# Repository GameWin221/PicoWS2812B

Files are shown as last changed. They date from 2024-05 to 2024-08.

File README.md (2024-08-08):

# PicoWS2812B

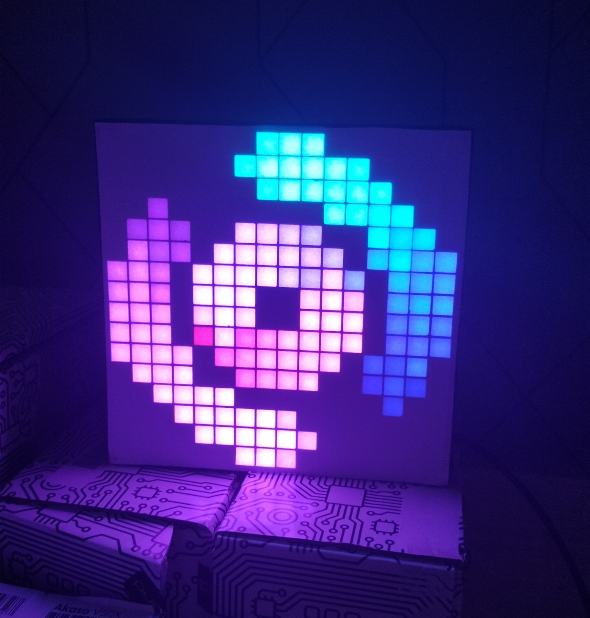
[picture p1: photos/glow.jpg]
glow


16x16 WS2812B matrix display controlled via Wi-Fi TCP socket with a Raspberry Pi Pico W. This project is my passion project but it also puts emphasis on performance and code readabilty in order to serve as a simple example for people learning. 

# Important Features
- Both 8 bits per-channel mode and 4 bits per-channel mode for lowering network usage and decreasing delay.
- TCP used instead of HTTP for additional performance.
- Seamless handling of client<->server connect / disconnect.
- Readable code that can easily be used for learning purposes.
- Images, Image sequences and GIFs can be stored in flash memory and played back offline with no interruptions.

# Controller
Any controller that uses **TCP sockets** and conforms to the **Packet Format** and the **Data Protocol** sections below will be compatible with the display. 

Take a look at the [working example of a compatible controller](https://github.com/GameWin221/pico-ws2812b-controller)

## Data Protocol
The display receives packets through a TCP socket open on port 4242 by deafault. (It can be changed)

1. Controller sends a valid packet (look at **Packet Format**) to the Pico W
2. Controller waits for a response from the Pico W
3. If the response reads exactly `"ACK"`, then the whole packet was sent and received succesfully.

After reading the correct response, the next packet can be sent immediately.

## Packet Format
Take a look at the [packet.hpp](src/packet.hpp) file to see all packet types. Mind the [default C/C++ struct alignment](https://en.wikipedia.org/wiki/Data_structure_alignment#Typical_alignment_of_C_structs_on_x86). 

The first byte (`uint8_t`) of a received packet is always the `data_type` field. Each packet type has its own unique data type.

RGB data is expected to be in the [row-major](https://en.wikipedia.org/wiki/Row-_and_column-major_order) order with (x:0, y:0) being the lower-left corner:
```
...       , ...       , ...
(x:0; y:2), (x:1; y:2), ...
(x:0; y:1), (x:1, y:1), ...
(x:0; y:0), (x:1, y:0), ...
```

8bpp (Full) RGB data layout:
```
data[0] , data[1] , data[2] , data[...]
RRRRRRRR, GGGGGGGG, BBBBBBBB, ...
```

4bpp (Half) RGB data layout:
```
data[0] , data[1] , data[2] , data[...]
RRRRGGGG, BBBBRRRR, GGGGBBBB, ...
```

## Working Example
The working example of a compatible controller can be found [here in this repository](https://github.com/GameWin221/pico-ws2812b-controller)

# Build
## Prerequisites
- Native GNU C++ compiler [(for example MinGW)](https://winlibs.com/) that is added to PATH
- [ARM GNU Toolchain](https://developer.arm.com/downloads/-/arm-gnu-toolchain-downloads) and the `PICO_TOOLCHAIN_PATH` environmental variable.
- [Pico SDK](https://github.com/raspberrypi/pico-sdk) and the `PICO_SDK_PATH` environmental variable.

## Command
Once the prerequisites are satisfied, run the following command:
```
mkdir build
cd build

cmake -G "MinGW Makefiles" .. 
make (ming32-make on Windows)
```

And copy the built .uf2 file to your Pico's Mass Storage

# Power Consumption
**Please double-check if your power supply can safely provide enough current at 5V. Note that not every WS2812B draws the same amount of current.**

Current draw was measured only at 0%, 12.5% and 25% brightness with the whole display set to RGB(255, 255, 255). Higher values were calculated by extrapolatating the measurements.

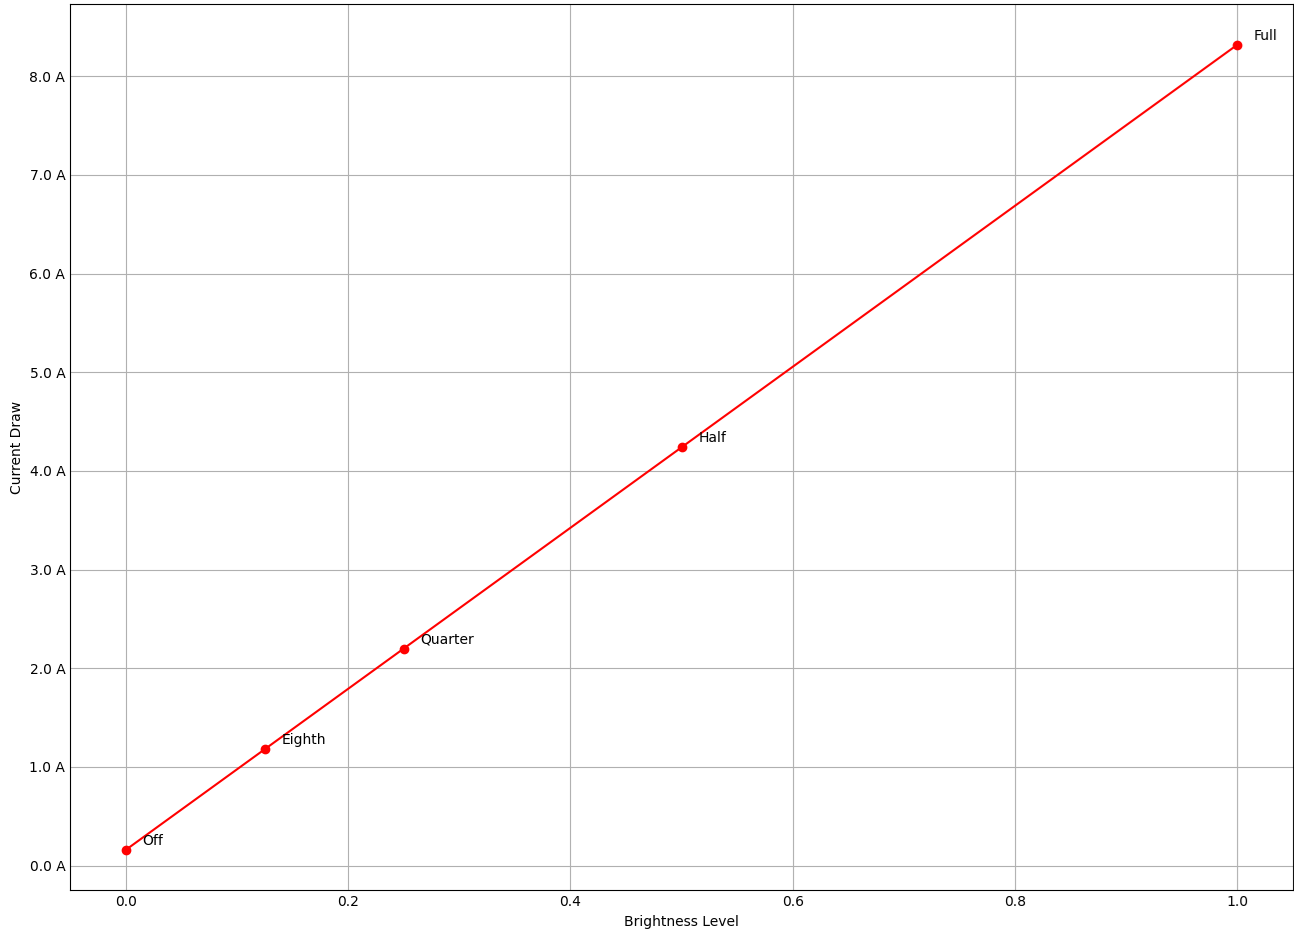
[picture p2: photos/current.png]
current


# Parts Required
- [16x16 WS2812B RGB LED Matrix](https://botland.store/led-strings-chains-matrices/6183-elastic-matrix-16x16-256-led-rgb-ws2812b-5904422374945.html)
- [Raspberry Pi Pico W](https://botland.store/raspberry-pi-pico-modules-and-kits/21574-raspberry-pi-pico-w-rp2040-arm-cortex-m0-cyw43439-wifi-5056561803173.html)
- [Short Breadboard](https://botland.store/breadoards/19942-breadboard-justpi-400-holes-5904422328627.html)
- 3 Male-Male Jumper Wires (or any other way to connect WS2812B to the Pico)
- [DC 5,5x2,1mm socket with quick connection](https://botland.store/quick-couplings/1804-dc-55x21mm-socket-with-quick-connection-5904422373238.html)
- A piece of white paper or thin plastic that works well as a light diffuser
- 3D printed frame and grid (both .stl files are in the `3dprints` directory)

## Assembly
- Put the WS2812B in between the printed `Frame.stl` and the printed `Grid.stl` so that it fits nicely
- Glue `Frame.stl` and `Grid.stl` together
- Glue the light diffuser to `Grid.stl` so that it fully covers the LEDs
- Stick the breadboard to the matrix's backside - inside `Frame.stl`
- Insert the DC socket into the dedicated hole and **correctly connect** the power cables of the LED matrix.
- Put the Raspberry Pi Pico W into the breadboard and **correctly connect** the jumper wires.

# Disclaimer
**I am not responsible for any physical damage caused by running this code. Use adequate brightness levels and double-check if your power supply can safely provide enough current in order to avoid any unwanted damage. Some WS2812B LED matrices may require more current than others. The TCP server accepts every incoming connection and every packet with no verification so it may potentially pose a threat to your local network's overall security.**

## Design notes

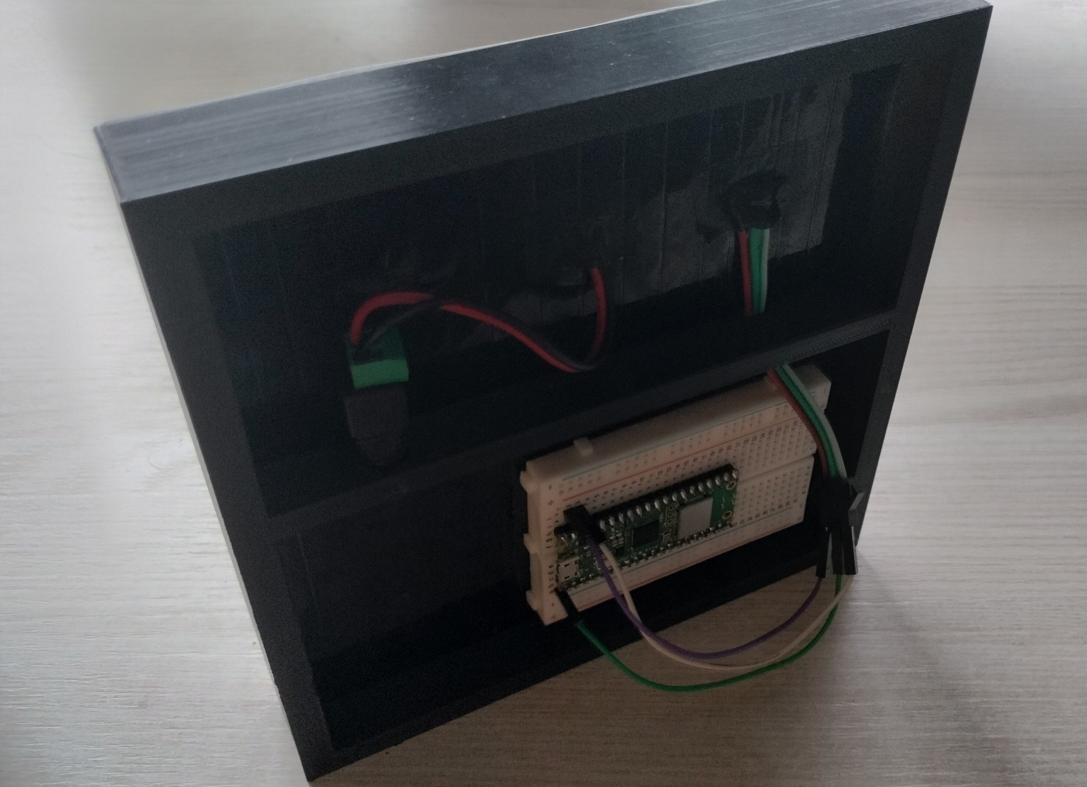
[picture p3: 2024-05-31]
photos/back.jpg

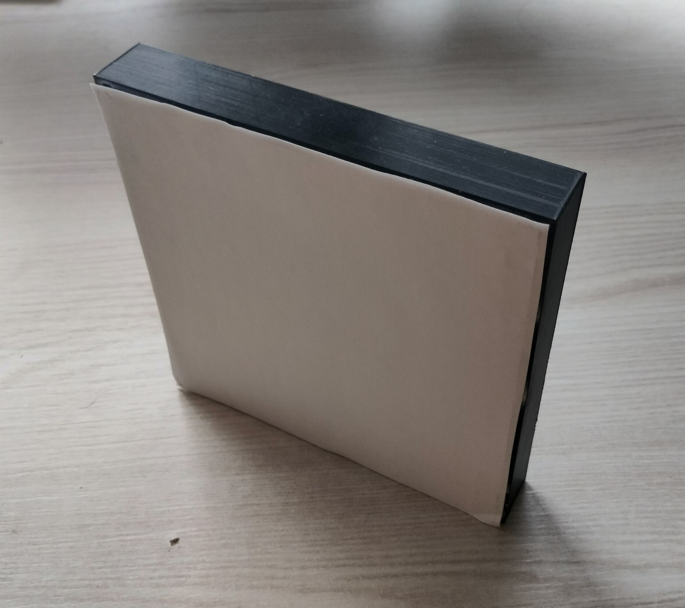
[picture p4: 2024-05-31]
photos/front.jpg

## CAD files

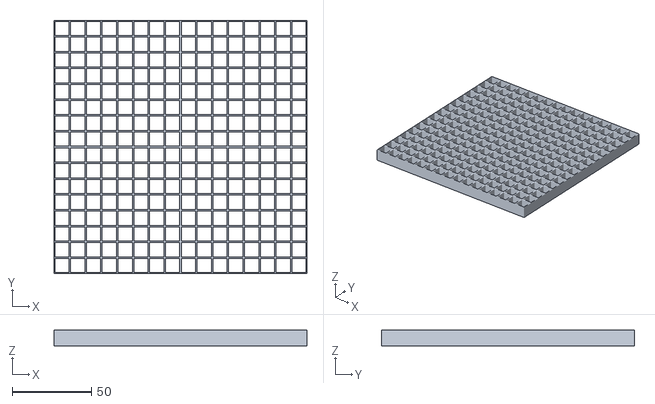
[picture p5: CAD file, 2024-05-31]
3dprints/Grid.stl
160.0 x 160.0 x 10.0

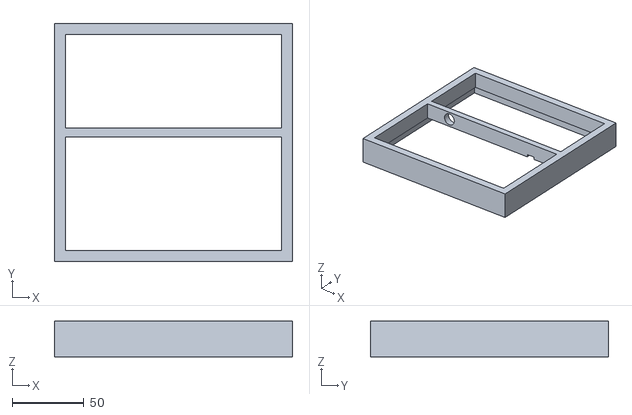
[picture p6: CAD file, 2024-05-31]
3dprints/Frame.stl
166.0 x 166.0 x 25.0

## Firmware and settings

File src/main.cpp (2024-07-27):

#include <pico/stdlib.h>
#include <pico/time.h>
#include <hardware/flash.h>
#include <hardware/sync.h>
#include <hardware/irq.h>

#include <string.h>

#include "packet.hpp"
#include "ws2812b.hpp"
#include "tcp_server.hpp"
#include "secrets.hpp" // WIFI_SSID "", WIFI_PASS ""

constexpr uint32_t DATA_PIN = 0u;
constexpr uint32_t SEVER_TIMEOUT_S = 8u;
constexpr uint16_t SEVER_PORT = 4242;

// 768KB offset
constexpr uint32_t FLASH_TARGET_OFFSET = (768u * 1024u);
static const uint8_t *flash_read_contents = (const uint8_t*)(XIP_BASE); // Adding the offset here makes read/write more inconsistent.

static repeating_timer_t flash_player_timer{};
static bool flash_player_running = false;

static uint16_t begin_frame_idx_inclusive{}; 
static uint16_t end_frame_idx_inclusive{}; 
static uint16_t time_interval_ms{};
static uint16_t current_frame_id{};

// Allows for better flash data packing and better flash wear. 
// Instead of using a whole sector per one frame, use one quarter of a sector per frame.
// Since one frame is 16*16*3 (768) bytes we only waste 25% of memory this way instead of 81.25%.
// It can be improved but it is good enough. We can store up to 1280 full 8bpp frames starting from 768KB offset.
static void write_flash_sector_quarter(uint32_t dst_sector_id, uint32_t dst_quarter_id, const uint8_t *data, uint32_t data_size) {
    if(data_size > FLASH_SECTOR_SIZE / 4u) {
        printf("write_flash_sector_quarter(uint32_t dst_sector_id, uint32_t dst_quarter_id, const uint8_t *data, uint32_t data_size) data_size cannot be larger than FLASH_SECTOR_SIZE / 4u\n");
        return;
    }

    if(dst_quarter_id > 3u) {
        printf("write_flash_sector_quarter(uint32_t dst_sector_id, uint32_t dst_quarter_id, const uint8_t *data, uint32_t data_size) dst_quarter_id msut be either 0, 1, 2 or 3\n");
        return;
    }

    const uint32_t quarter_size = FLASH_SECTOR_SIZE / 4;

    uint32_t dst_sector_offset = dst_sector_id * FLASH_SECTOR_SIZE;
    uint32_t dst_quarter_offset = dst_quarter_id * quarter_size;

    bool quarter_erased[4] = { true, true, true, true };

    for(uint32_t i{}; i < 4u; ++i) {
        for(uint32_t j{}; j < quarter_size; ++j) {
            if (flash_read_contents[FLASH_TARGET_OFFSET + dst_sector_offset + (i * quarter_size) + j] != 0xFF) {
                quarter_erased[i] = false;
                break;
            }
        }
    }

    uint32_t interrupts = save_and_disable_interrupts();

    if(quarter_erased[dst_quarter_id]) {
        flash_range_program(FLASH_TARGET_OFFSET + dst_sector_offset + dst_quarter_offset, data, data_size);
    } else {
        static uint8_t sector_copy[FLASH_SECTOR_SIZE];
        
        memcpy(sector_copy, &flash_read_contents[FLASH_TARGET_OFFSET + dst_sector_offset], FLASH_SECTOR_SIZE);
        
        flash_range_erase(FLASH_TARGET_OFFSET + dst_sector_offset, FLASH_SECTOR_SIZE);

        for(uint32_t i{}; i < 4u; ++i) {
            uint32_t src_quarter_offset = i * quarter_size;

            if(i != dst_quarter_id && !quarter_erased[i]) {
                // Restore old 3 quarters. No need to restore erased quarters.
                flash_range_program(FLASH_TARGET_OFFSET + dst_sector_offset + src_quarter_offset, &sector_copy[src_quarter_offset], quarter_size);
            } else {
                // Write new quarter data
                flash_range_program(FLASH_TARGET_OFFSET + dst_sector_offset + src_quarter_offset, data, data_size);
            }
        }
    }

    restore_interrupts(interrupts);
}

static bool flash_player_timer_callback(repeating_timer_t *rt) {
    WS2812B *led_matrix = (WS2812B*)rt->user_data;

    uint32_t current_frame_offset = (uint32_t)current_frame_id * FLASH_SECTOR_SIZE / 4u;

    for(uint32_t x{}; x < 16u; ++x) {
        for(uint32_t y{}; y < 16u; ++y) {
            uint32_t idx = y * 16u + x;

            led_matrix->set_pixel(x, y, 
                flash_read_contents[FLASH_TARGET_OFFSET + idx * 3u + 0u + current_frame_offset],
                flash_read_contents[FLASH_TARGET_OFFSET + idx * 3u + 1u + current_frame_offset],
                flash_read_contents[FLASH_TARGET_OFFSET + idx * 3u + 2u + current_frame_offset]
            );
        }
    }

    led_matrix->update_display();

    // Wrap back to the beginning
    if((++current_frame_id) > end_frame_idx_inclusive) {
        current_frame_id = begin_frame_idx_inclusive;
    }

    return true;
}

static void on_buffer_ready(const uint8_t *buf, WS2812B &led_matrix) {
    // Any incoming data will interrupt the currently playing flash player
    if(flash_player_running) {
        cancel_repeating_timer(&flash_player_timer);
        flash_player_running = false;
    }

    uint8_t buf_data_type = buf[0];

    switch(buf_data_type) {
        case DATA_TYPE_FULL: {
            const PacketFull *p = (const PacketFull*)buf;

            for(uint32_t x{}; x < 16u; ++x) {
                for(uint32_t y{}; y < 16u; ++y) {
                    uint32_t idx = y * 16u + x;

                    led_matrix.set_pixel(x, y, 
                        p->data[idx * 3u + 0u],
                        p->data[idx * 3u + 1u],
                        p->data[idx * 3u + 2u]
                    );
                }
            }

            led_matrix.update_display();
        }   break;

        case DATA_TYPE_HALF: {
            const PacketHalf *p = (const PacketHalf*)buf;

            for(uint32_t x{}; x < 16u; ++x) {
                for(uint32_t y{}; y < 16u; ++y) {
                    uint32_t idx = y * 16u + x;

                    uint8_t r = (idx % 2u == 0u) ? ((p->data[idx * 3u / 2u + 0u] & 0xf0) >> 4) :  (p->data[idx * 3u / 2u + 0u] & 0x0f);
                    uint8_t g = (idx % 2u == 0u) ?  (p->data[idx * 3u / 2u + 0u] & 0x0f)       : ((p->data[idx * 3u / 2u + 1u] & 0xf0) >> 4);
                    uint8_t b = (idx % 2u == 0u) ? ((p->data[idx * 3u / 2u + 1u] & 0xf0) >> 4) :  (p->data[idx * 3u / 2u + 1u] & 0x0f);

                    // Unpack from 4 bits to 8 bits
                    led_matrix.set_pixel(x, y, r << 4, g << 4, b << 4);
                }
            }

            led_matrix.update_display();
        }   break;

        case DATA_TYPE_WRITE_FLASH: {
            const PacketWriteFlash *p = (const PacketWriteFlash*)buf;

            uint32_t dst_sector = (uint32_t)p->frame_idx / 4u;
            uint32_t dst_quarter = (uint32_t)p->frame_idx % 4u;

            write_flash_sector_quarter(dst_sector, dst_quarter, p->data, 16u * 16u * 3u);
        } break;

        case DATA_TYPE_PLAY_FLASH: {
            const PacketPlayFlash *p = (const PacketPlayFlash*)buf;

            begin_frame_idx_inclusive = p->begin_frame_idx_inclusive;
            end_frame_idx_inclusive = p->end_frame_idx_inclusive;
            time_interval_ms = p->time_interval_ms;

            if(begin_frame_idx_inclusive > end_frame_idx_inclusive) {
                printf("main(): begin_frame_idx_inclusive cannot be greater than end_frame_idx_inclusive!\n");
                begin_frame_idx_inclusive = 0u;
                end_frame_idx_inclusive = 0u;
                
                break;
            }

            if(!add_repeating_timer_ms(-((int32_t)time_interval_ms), flash_player_timer_callback, &led_matrix, &flash_player_timer)) { 
                printf("main(): Failed to create flash_player_timer!\n");

                break;
            } else {
                flash_player_running = true;
            }
        }   break;

        default:
            printf("main(): Incorrect buf_data_type!\n");
            break;
    }
}

int main() {
    stdio_init_all();

    if (cyw43_arch_init()) {
        printf("main(): Failed to initialise cyw43_arch!\n");
        return 1;
    }
    
    cyw43_arch_enable_sta_mode();

    WS2812B led_matrix(DATA_PIN, LEDBrightness::Half);
    led_matrix.fill(64, 0, 0);
    led_matrix.update_display();

    printf("Connecting to Wi-Fi...\n");

    while(cyw43_arch_wifi_connect_timeout_ms(WIFI_SSID, WIFI_PASS, CYW43_AUTH_WPA2_AES_PSK, 10000u)) {
        printf("Failed to connect to Wi-Fi. Retrying...\n");
    }

    printf("Connected to Wi-Fi.\n");

    led_matrix.fill(64, 64, 0);
    led_matrix.update_display();

    TCPServer server{};
    if(!server.start(SEVER_PORT, SEVER_TIMEOUT_S)) {
        printf("main(): Failed to start the server. Retrying..\n");

        led_matrix.fill(0, 64, 64);
        led_matrix.update_display();

        cyw43_arch_deinit();

        return 1;
    }
    
    printf("Server started successfully!\n");
    
    led_matrix.fill(0, 64, 0);
    led_matrix.update_display();

    while(server.is_running()) {  
        cyw43_arch_poll();
        
        // Handle packets from the main thread to avoid problems (e.g. writing to flash)
        const uint8_t *buf = server.get_ready_buffer();
        if(buf != nullptr) {
            on_buffer_ready(buf, led_matrix);
        }

        cyw43_arch_wait_for_work_until(make_timeout_time_ms(100));
    }

    cyw43_arch_deinit();
}

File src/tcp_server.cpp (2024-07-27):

#include "tcp_server.hpp"
#include "packet.hpp"

// Based on the official picow_tcp_server.c example:
// https://github.com/raspberrypi/pico-examples/blob/master/pico_w/wifi/tcp_server/picow_tcp_server.c

bool TCPServer::start(uint16_t port, uint8_t _timeout_time_s) {
    printf("Starting server at %s:%u\n", ip4addr_ntoa(netif_ip4_addr(netif_list)), port);

    tcp_pcb *pcb = tcp_new_ip_type(IPADDR_TYPE_ANY);
    if (!pcb) {
        printf("TCPServer::start(uint16_t port): Failed to create the server pcb\n");
        return false;
    }

    if (tcp_bind(pcb, nullptr, port)) {
        printf("TCPServer::start(uint16_t port): Failed to bind to port: %u\n", port);
        return false;
    }
    
    server_pcb = tcp_listen_with_backlog(pcb, 1);
    if (!server_pcb) {
        printf("TCPServer::start(uint16_t port): Failed to listen for incoming clients.\n");

        tcp_close(pcb);

        return false;
    }

    timeout_time_s = _timeout_time_s;

    tcp_arg(server_pcb, this);
    tcp_accept(server_pcb, TCPServer::server_connect_client);

    return true;
}
void TCPServer::stop() {
    return server_close(this);
}

const uint8_t *TCPServer::get_ready_buffer() {
    if(is_buffer_ready) {
        is_buffer_ready = false;
        
        return in_buffer;
    } else {
        return nullptr;
    }
}

err_t TCPServer::server_send_data(void *arg, tcp_pcb *tpcb, const void *data, uint16_t data_size) {
    TCPServer *state = (TCPServer*)arg;

    cyw43_arch_lwip_check();

    if (tcp_write(tpcb, data, data_size, TCP_WRITE_FLAG_COPY) != ERR_OK) {
        printf("TCPServer::server_send_data(void *arg, tcp_pcb *tpcb, const void *data, uint16_t data_size): Server failed to send bytes!\n");
        return ERR_MEM;
    }

    return ERR_OK;
}

err_t TCPServer::server_recv(void *arg, tcp_pcb *tpcb, pbuf *p, err_t err) {
    TCPServer *state = (TCPServer*)arg;
    if (!p) {
        server_disconnect_client(arg);
        return ERR_OK; // Safely handled disconnect
    }

    cyw43_arch_lwip_check();

    if (p->tot_len > 0u) {
        uint16_t bytes_read = pbuf_copy_partial(p, (void*)(state->in_buffer + state->in_received_count), p->tot_len, 0);
        pbuf_free(p);

        if(bytes_read == 0u) {
            printf("TCPServer::server_recv(void *arg, tcp_pcb *tpcb, pbuf *p, err_t err): Server failed to read bytes!\n");

            return ERR_MEM;
        }
        
        //printf("Server read: %u bytes, err: %d\n", (uint32_t)bytes_read, err);

        state->in_received_count += bytes_read;

        tcp_recved(tpcb, bytes_read);

        // Whole incoming packet received
        if(state->in_received_count == get_data_type_size(state->in_buffer[0])) {
            state->in_received_count = 0u;
            state->is_buffer_ready = true;

            // Respond with "ACK" message
            const char* ack_message = "ACK";
            return server_send_data(arg, state->client_pcb, ack_message, strlen(ack_message) + 1u);
        }
    } else {
        pbuf_free(p);
    }

    return ERR_OK;
}

err_t TCPServer::server_poll(void *arg, tcp_pcb *tpcb) {
    TCPServer *state = (TCPServer*)arg;

    printf("TCPServer::server_poll(void *arg, tcp_pcb *tpcb): No communication with client for more than %u seconds!\n", state->timeout_time_s);

    server_disconnect_client(arg);

    return ERR_OK;
}

void TCPServer::server_close(void *arg) {
    TCPServer *state = (TCPServer*)arg;

    server_disconnect_client(arg);

    if (state->server_pcb) {
        tcp_arg(state->server_pcb, nullptr);
        tcp_close(state->server_pcb);

        state->server_pcb = nullptr;
    }
}

void TCPServer::server_err(void *arg, err_t err) {
    // Failsafe
    if(err == ERR_CLSD || err == ERR_ABRT || err == ERR_RST || err == ERR_TIMEOUT || err == ERR_RTE) {
        server_disconnect_client(arg);  // Safely handled disconnect
        return; 
    }
    
    printf("TCPServer::server_err(void *arg, err_t err): code:%d\n", (int)err);
    server_close(arg);
}

err_t TCPServer::server_connect_client(void *arg, tcp_pcb *client_pcb, err_t err) {
    TCPServer *state = (TCPServer*)arg;
    if (err != ERR_OK || client_pcb == nullptr) {
        printf("TCPServer::server_connect_client(void *arg, tcp_pcb *client_pcb, err_t err): Failed to connect with an incoming client!\n");
        return ERR_VAL;
    }

    state->client_pcb = client_pcb;
    
    tcp_arg(state->client_pcb, state);
    tcp_recv(state->client_pcb, TCPServer::server_recv);
    tcp_poll(state->client_pcb, TCPServer::server_poll, state->timeout_time_s * 2u);
    tcp_err(state->client_pcb, TCPServer::server_err);

    printf("Client connected\n");

    cyw43_arch_gpio_put(CYW43_WL_GPIO_LED_PIN, 1);

    return ERR_OK;
}
void TCPServer::server_disconnect_client(void *arg) {
    TCPServer *state = (TCPServer*)arg;
    if(state->client_pcb == nullptr) {
        return;
    }
    
    tcp_arg(state->client_pcb, nullptr);
    tcp_poll(state->client_pcb, nullptr, 0);
    tcp_recv(state->client_pcb, nullptr);
    tcp_err(state->client_pcb, nullptr);

    if (tcp_close(state->client_pcb) != ERR_OK) {
        printf("TCPServer::server_disconnect_client(void *arg): tcp_close failed, calling tcp_abort\n");
        tcp_abort(state->client_pcb);
    }

    state->client_pcb = nullptr;

    printf("Client disconnected\n");

    cyw43_arch_gpio_put(CYW43_WL_GPIO_LED_PIN, 0);
}
